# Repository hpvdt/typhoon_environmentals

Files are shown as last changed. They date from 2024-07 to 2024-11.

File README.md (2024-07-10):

# Typhoon Environmentals

General template repository for our hardware projects, especially one-off and self-contained projects like custom test equipment. This template assumes that the hardware is being designed in KiCad.

## Organization

Pretty self-explanitory, put hardware related files into the `hardware` folder, firmware in the `firmware` folder. Other folders can be added as needed: for example a `media` folder is handy for storing pictures related to a project which can be used in documentation.

## Conventions

Partly for consistency, partly for functionality; please follow the following conventions:

- Try to keep folder names to single words and all lowercase
- Use underscores to separate words in names (e.g. `board_rev1`). **DO NOT USE SPACES! ESPECIALLY FOR FOLDERS CONTAINING CODE!** Spaces in file paths may cause issues in compilers and such so best to avoid them entirely.

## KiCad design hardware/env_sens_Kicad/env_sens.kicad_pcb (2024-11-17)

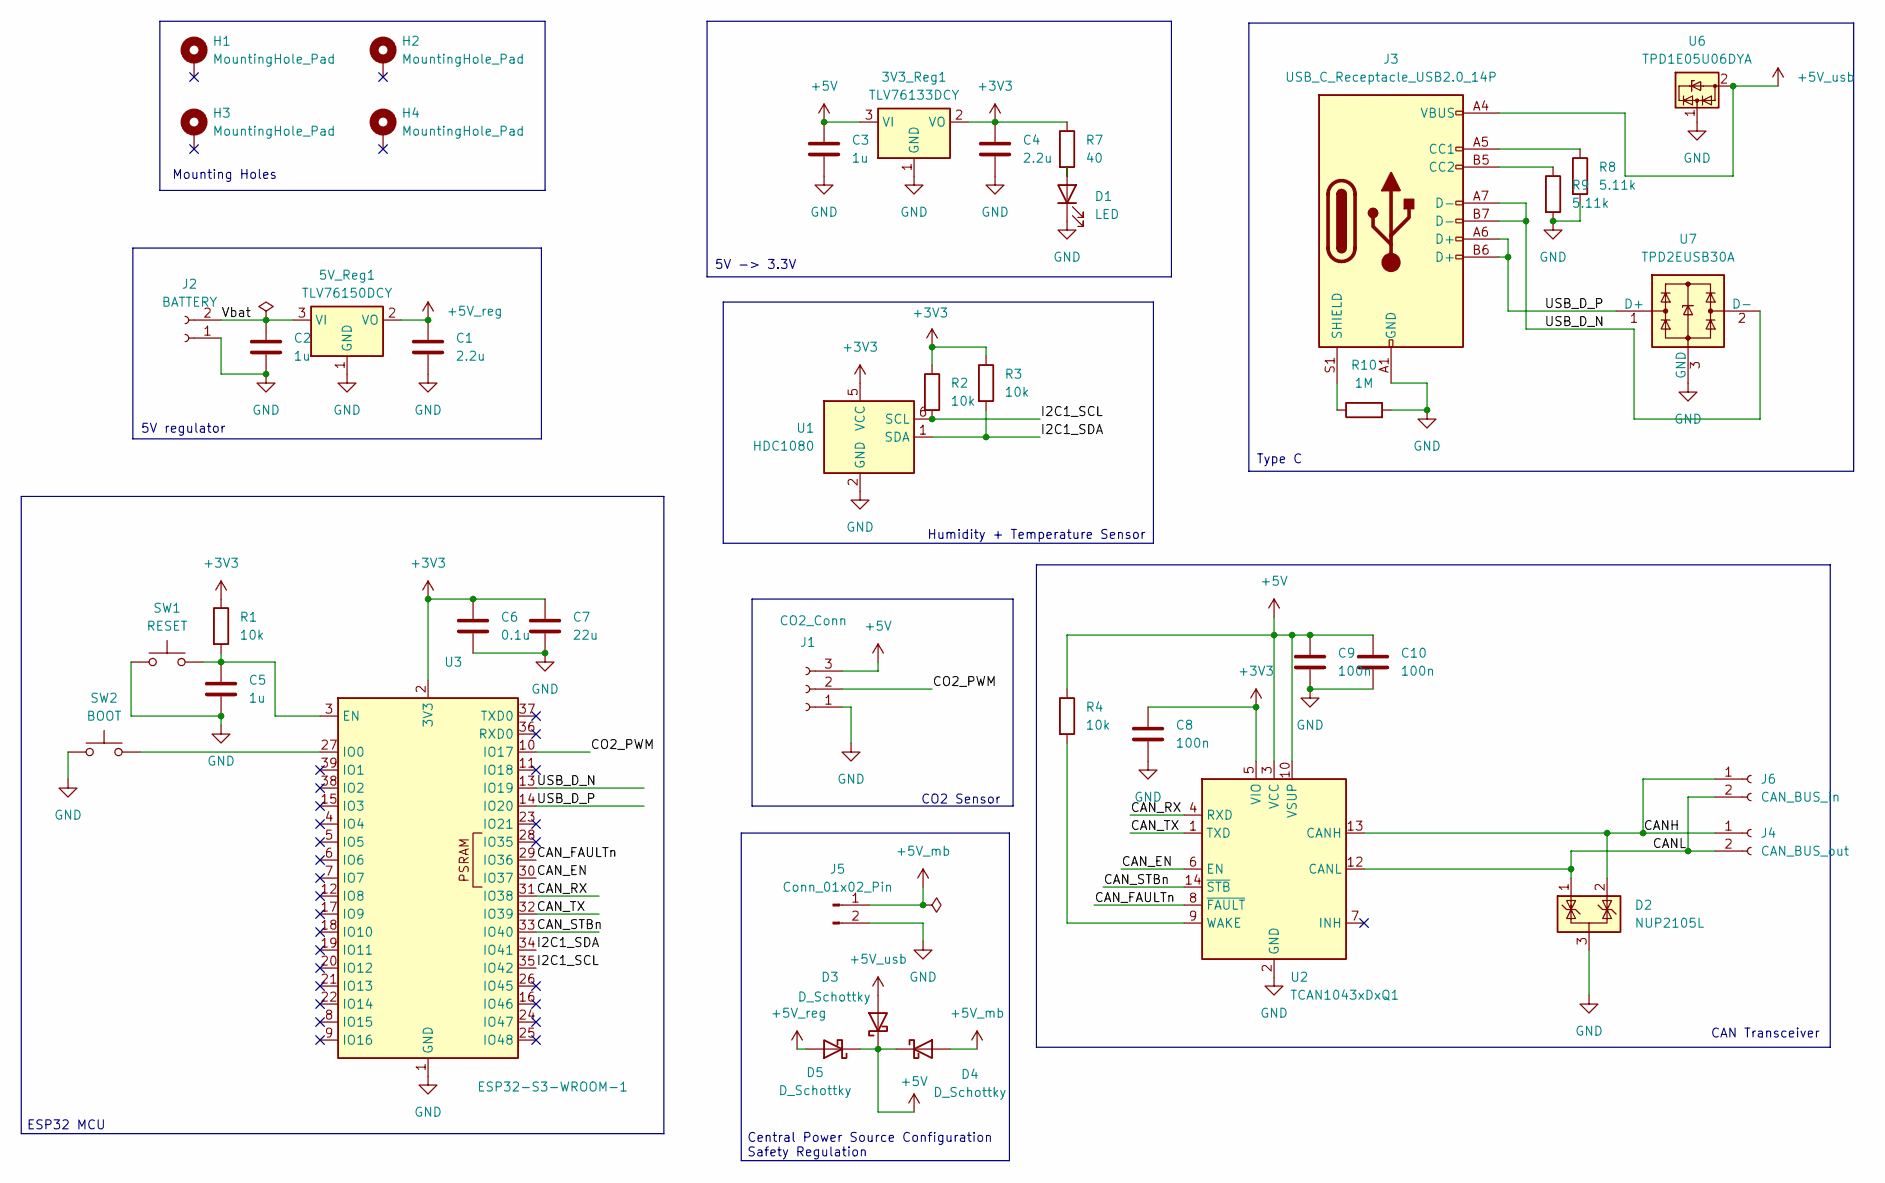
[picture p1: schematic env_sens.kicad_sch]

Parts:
3V3_Reg1: TLV76133DCY; SOT-223-3_TabPin2
5V_Reg1: TLV76150DCY; SOT-223-3_TabPin2
C1, C4: 2.2u; C_0805_2012Metric_Pad1.18x1.45mm_HandSolder
C2, C3, C5: 1u; C_0805_2012Metric_Pad1.18x1.45mm_HandSolder
C6: 0.1u; C_0805_2012Metric_Pad1.18x1.45mm_HandSolder
C7: 22u; C_0805_2012Metric_Pad1.18x1.45mm_HandSolder
C8, C9, C10: 100n; C_0805_2012Metric_Pad1.18x1.45mm_HandSolder
D1: LED; LED_0805_2012Metric_Pad1.15x1.40mm_HandSolder
D2: NUP2105L; SOT-23
D3, D4, D5: D_Schottky; D_SOD-123
H1, H2, H3, H4: MountingHole_Pad; MountingHole_2.7mm_M2.5
J1: CO2_Conn; JST_XH_S3B-XH-A_1x03_P2.50mm_Horizontal
J2: BATTERY; AMASS_XT30PW-M_1x02_P2.50mm_Horizontal
J3: USB_C_Receptacle_USB2.0_14P; USB_C_Receptacle_Amphenol_12401610E4-2A
J4: CAN_BUS_out; JST_EH_S2B-EH_1x02_P2.50mm_Horizontal
J5: Conn_01x02_Pin; JST_EH_S2B-EH_1x02_P2.50mm_Horizontal
J6: CAN_BUS_in; JST_EH_S2B-EH_1x02_P2.50mm_Horizontal
R1, R2, R3, R4: 10k; R_0805_2012Metric_Pad1.20x1.40mm_HandSolder
R7: 40; R_0805_2012Metric_Pad1.20x1.40mm_HandSolder
R8, R9: 5.11k; R_0805_2012Metric_Pad1.20x1.40mm_HandSolder
R10: 1M; R_0805_2012Metric_Pad1.20x1.40mm_HandSolder
SW1: RESET; SW_PUSH_6mm
SW2: BOOT; SW_PUSH_6mm
U1: HDC1080; Texas_PWSON-N6
U2: TCAN1043xDxQ1; SOIC-14_3.9x8.7mm_P1.27mm
U3: ESP32-S3-WROOM-1
U6: TPD1E05U06DYA; D_SOD-523
U7: TPD2EUSB30A; Texas_DRT-3

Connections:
+3V3: 3V3_Reg1.2 (VO), C4.1, C6.1, C7.1, C8.1, R1.1, R2.1, R3.1, R7.1, U1.5 (VCC), U2.5 (VIO), U3.2 (3V3)
+5V: 3V3_Reg1.3 (VI), C3.1, C9.1, C10.1, D3.1 (K), D4.1 (K), D5.1 (K), J1.3, R4.1, U2.3 (VCC), U2.10 (VSUP)
+5V_mb: D4.2 (A), J5.1
+5V_reg: 5V_Reg1.2 (VO), C1.1, D5.2 (A)
+5V_usb: D3.2 (A), J3.A4 (VBUS), J3.A9 (VBUS), J3.B4 (VBUS), J3.B9 (VBUS), U6.2 (GND)
/CANH: D2.2 (K), J4.1, J6.1, U2.13 (CANH)
/CANL: D2.1 (K), J4.2, J6.2, U2.12 (CANL)
/CAN_EN: U2.6 (EN), U3.30 (IO37)
/CAN_FAULTn: U2.8 (~FAULT), U3.29 (IO36)
/CAN_RX: U2.4 (RXD), U3.31 (IO38)
/CAN_STBn: U2.14 (~STB), U3.33 (IO40)
/CAN_TX: U2.1 (TXD), U3.32 (IO39)
/CO2_PWM: J1.2, U3.10 (IO17)
/I2C1_SCL: R2.2, U1.6 (SCL), U3.35 (IO42)
/I2C1_SDA: R3.2, U1.1 (SDA), U3.34 (IO41)
/USB_D_N: J3.A7 (D-), J3.B7 (D-), U3.13 (IO19), U7.2 (D-)
/USB_D_P: J3.A6 (D+), J3.B6 (D+), U3.14 (IO20), U7.1 (D+)
/Vbat: 5V_Reg1.3 (VI), C2.1, J2.2
GND: 3V3_Reg1.1 (GND), 5V_Reg1.1 (GND), C1.2, C2.2, C3.2, C4.2, C5.2, C6.2, C7.2, C8.2, C9.2, C10.2, D1.1 (K), D2.3 (A), J1.1, J2.1, J3.A1 (GND), J3.A12 (GND), J3.B1 (GND), J3.B12 (GND), J5.2, R8.2, R9.2, R10.2, SW1.1, SW2.1, U1.2 (GND), U2.2 (GND), U3.1 (GND), U3.40 (GND), U3.41 (GND), U6.1 (I/O), U7.3 (GND)
unnamed: D1.2 (A), R7.2
unnamed: J3.A5 (CC1), R8.1
unnamed: J3.B5 (CC2), R9.1
unnamed: J3.S1 (SHIELD), R10.1
unnamed: R4.2, U2.9 (WAKE)
unnamed: C5.1, R1.2, SW1.2, U3.3 (EN)
unnamed: SW2.2, U3.27 (IO0)

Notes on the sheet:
Mounting Holes
ESP32 MCU
Type C
CAN Transceiver
Humidity + Temperature Sensor
5V -> 3.3V
CO2 Sensor
5V regulator
Central Power Source Configuration Safety Regulation

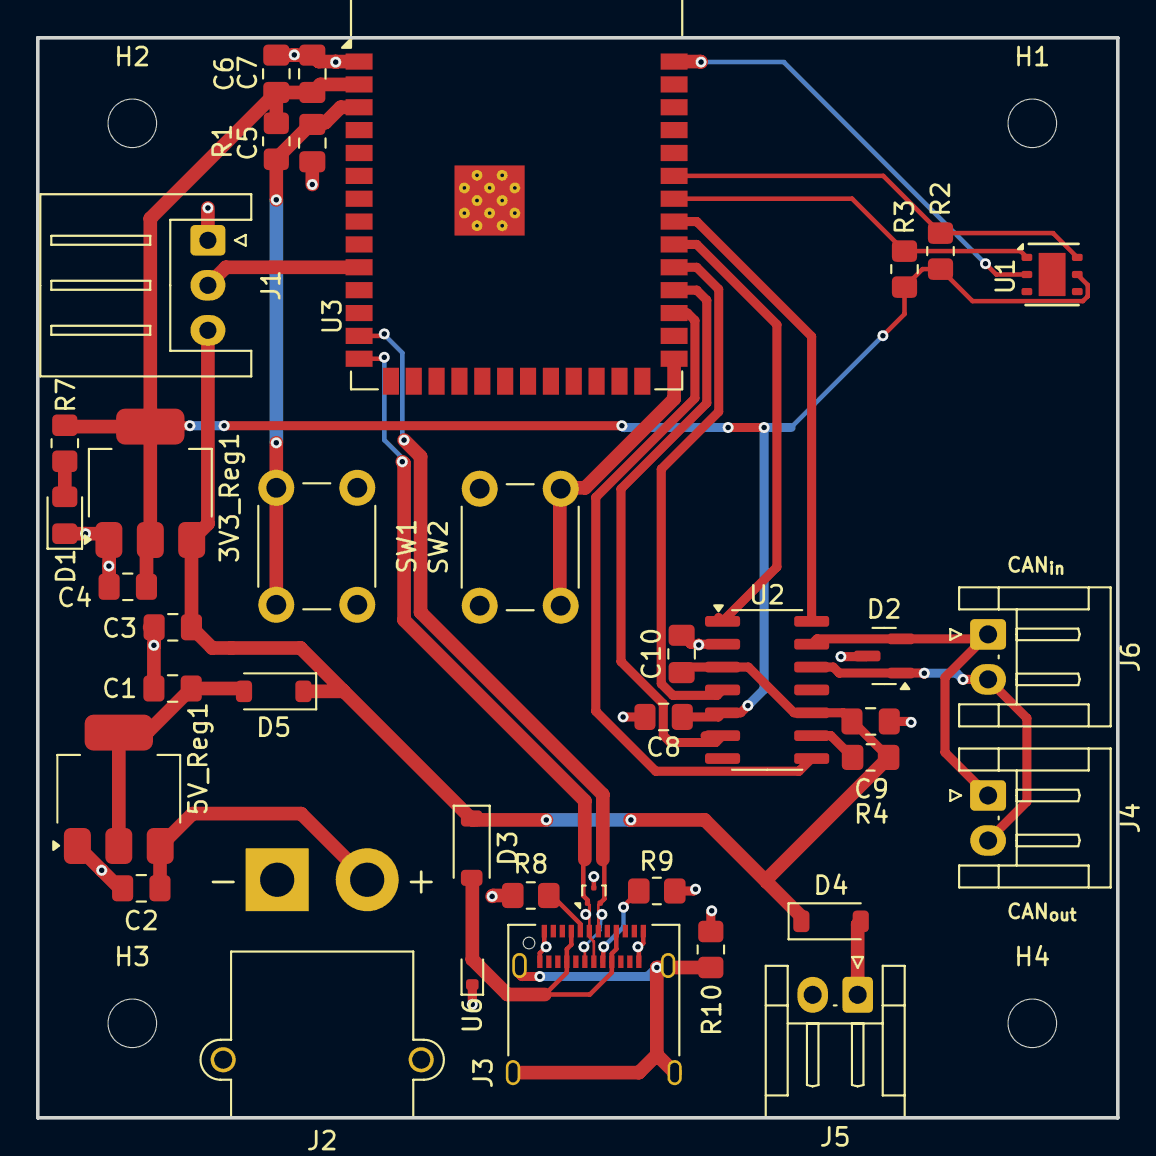
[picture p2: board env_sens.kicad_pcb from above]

Board: 2 copper layers, 60.0 x 60.0 mm, 42 parts (0 on the bottom side), 26 nets.

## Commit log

2024-10-05 Uploaded files from typhoon electronics
    [env_sens.kicad_pcb, env_sens.kicad_sch]
2024-10-14 Added the central power source configuration and added some comments
    [env_sens.kicad_pcb]
2024-10-14 Added central power source configuration from mother board
    Central power source configuration from mother board + safety regulation
    [env_sens.kicad_pcb, env_sens.kicad_sch]
2024-10-19 Changed MB input voltage to 5V
    [env_sens.kicad_sch]
2024-11-04 Updated layout with schematic changes
    [env_sens.kicad_pcb, env_sens.kicad_sch]
2024-11-17 Replaced with schottkey dioides & did production files
    [env_sens.kicad_pcb, env_sens.kicad_sch]
